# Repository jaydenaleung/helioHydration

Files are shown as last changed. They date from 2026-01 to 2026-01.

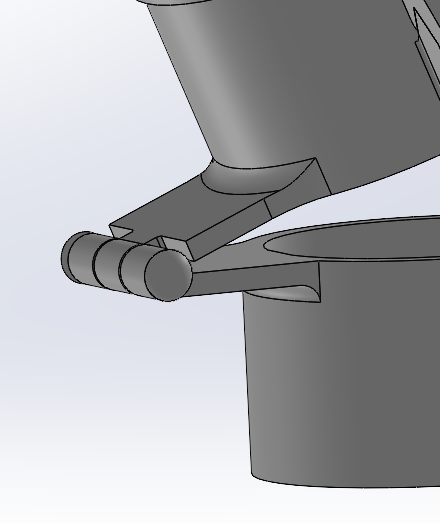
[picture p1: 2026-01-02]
filter/cad/production/render-5.png

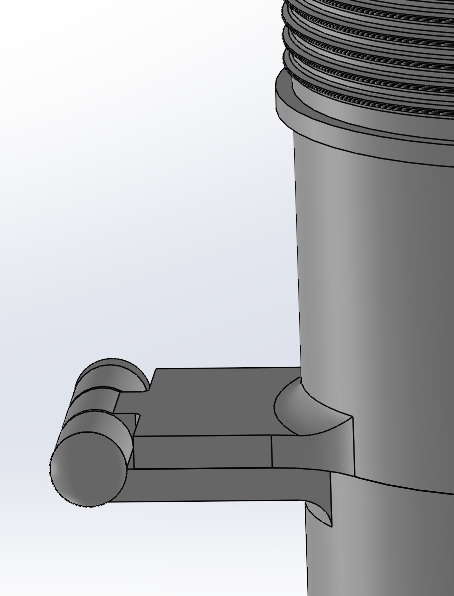
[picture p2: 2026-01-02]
filter/cad/production/render-2.png

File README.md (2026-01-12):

# Helio Hydration - 3-Stage SODIS-Enhancing Water Bottle
Three-stage solar water disinfection (SODIS)-enhancing low-cost water bottle for NGO distribution to underserved and impoverished areas globally.



## Overview

This is a custom-designed water bottle to enhance solar water disinfection, a process where people utilize the sun's UV rays to kill bacteria in contaminated water, especially in places without access to clean water. The goal of this project is to design an efficient device that NGOs can buy and distribute to crisis areas around the world. The three stages are fiber membrane filtration, SODIS enhancement via clearer plastic materials, reflection, and heat-trapping, and indication/readiness tracking.

**Total time spent: 25.5 hours**

## Why I Created This Project

This project was created with a team for the Conrad Challenge: Water Challenge (though we decided not to submit it in the end). However, all the work for this Blueprint project was entirely my own - the team helped with other areas of the research and project. When brainstorming, we wanted to create a project that would have a 'wow' factor for Conrad Challenge judges, a real impact on the world and global issues, and a technically challenging aspect. After conducting much research around the field, we settled on this idea because we saw that SODIS relied too much on having perfectly sunny weather and non-turbid water. Indication was also an issue since people didn't know when it was truly disinfected.

## How It Works & Implementation

The mechanical structure is comprised of a body, a filter, and an indicator with its housing. The body is parabolic 100mm from the ground, and cylindrical until it reaches a height of ~227mm. Its largest diameter is 120mm. The filter mechanism is a clamp with a twist cap for the membrane fiber filter. The indicator uses the DS18B20 temperature sensor in conjunction with the GUVA-S12SD to calculate log reductions of E. coli.

Using the OneWire and DallasTemperature Arduino libraries, both the measured voltage from the UV photodiode sensor and the Celsius temperature from the temperature are gleaned. The following theoretical function calculates the number of log reductions at a specific time:



For the Arduino MCU, this function is used (using a discrete delta t):



I quite enjoyed applying the volume revolution and bacterial decay formulas I learned from AP Calculus BC this year. I've never really had a project where my class knowledge helped me so much. See the journal for more details.

## Bill of Materials (BOM)

| Name | Quantity | Price (per part) | Link |
| --- | --- | --- | --- |
| GUVA-S12SD UV Sensor Photodiode | 1 | $1.76 | https://www.aliexpress.us/item/3256806350705812.html |
| DS18B20 Temperature Sensor | 1 | $0.2328 | https://jlcpcb.com/partdetail/MSKSEMI-DS18B20MS/C5379069 |
| Ceramic Capacitor SMD | 2 | $0.0007 | https://jlcpcb.com/partdetail/1907-0402CG220J500NT/C1555 |
| Electrolytic Capacitor SMD | 2 | $0.0332 | https://jlcpcb.com/partdetail/14236-CL31A106KBHNNNE/C13585 |
| 4.7kΩ SMD Resistor | 1 | $0.0006 | https://jlcpcb.com/partdetail/26643-0402WGF4701TCE/C25900 |
| 10kΩ SMD Resistor | 1 | $0.001 | https://jlcpcb.com/partdetail/16079-0603WAJ0103T5E/C15401 |
| ATMEGA328P-PU Microcontroller | 1 | $2.2431 | https://jlcpcb.com/partdetail/MicrochipTech-ATMEGA328PPU/C33901 |
| LM7805-TO220 Voltage Regulator | 1 | $0.2084 | https://jlcpcb.com/partdetail/6334298-LM7805CT/C5444281 |
| Crystal Oscillator 16MHz | 1 | $0.1038 | https://jlcpcb.com/partdetail/TAITIENElec-XIHCELNANF16MHZ/C295075 |
| Probe Housing | 1 | $0.3170 | https://www.aliexpress.us/item/3256807782132862.html |
| Epoxy resin | ~1 mL | $0.01 | https://www.walmart.com/ip/Epoxy-Resin-1-Gallon-Kit-Art-Resin-for-DIY-Jewelry-Tabletops-Crystal-Clear-High-Performance-Resin-Epoxy/5478464246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\_27795 |
| Membrane fiber filter | 1 | $0.29 | https://grupovoces.com/products/47mm-glass-fiber-filters-advantec-gc-90-100-pk-advantec |
| Clarified polypropylene (PP) | ~7.5 g | $0.0075 | Would need to contact a factory or ODM. Price taken from internet averages. |
| JLCPCB PCB | 1 | $1.06 ($7.45 with PCBA) | https://jlcpcb.com/ |
| **Total** | | | **$6.34**/bottle ($12.73 with PCBA) |

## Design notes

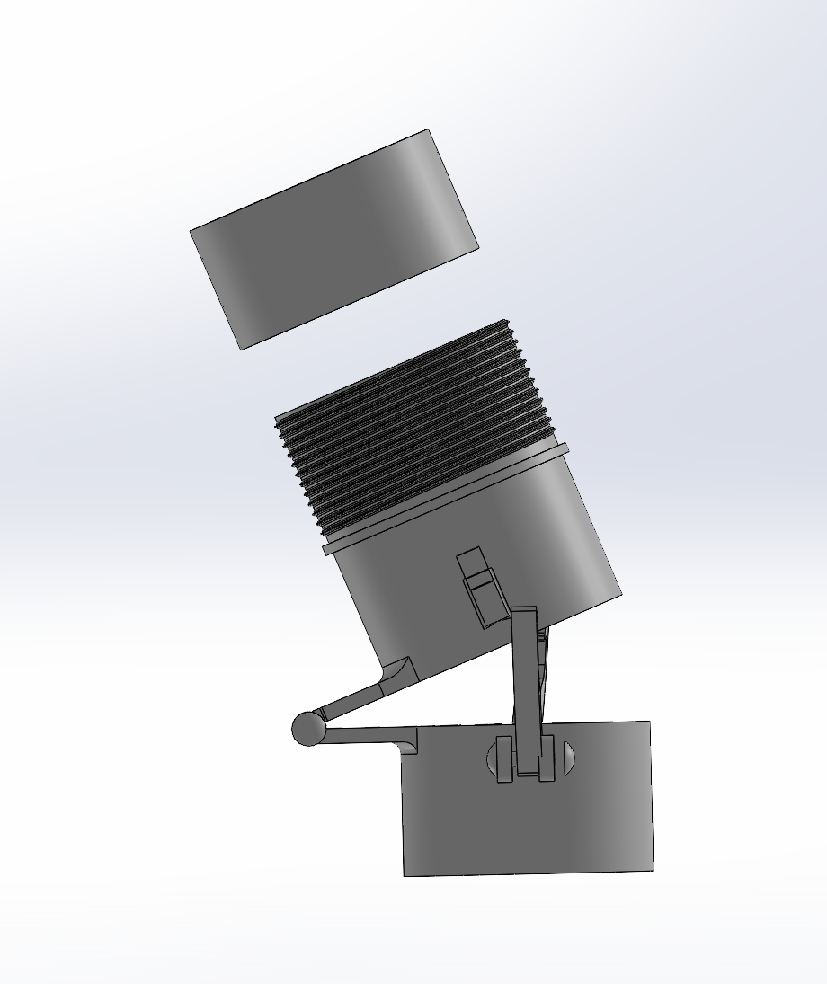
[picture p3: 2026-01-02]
filter/cad/production/render-7.png

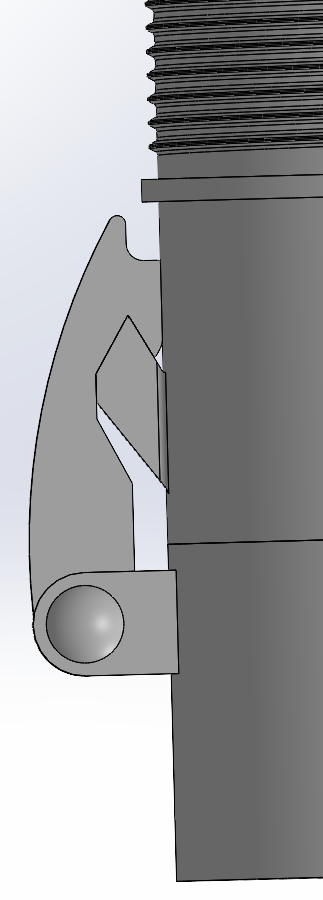
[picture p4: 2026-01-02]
filter/cad/production/render-3.png

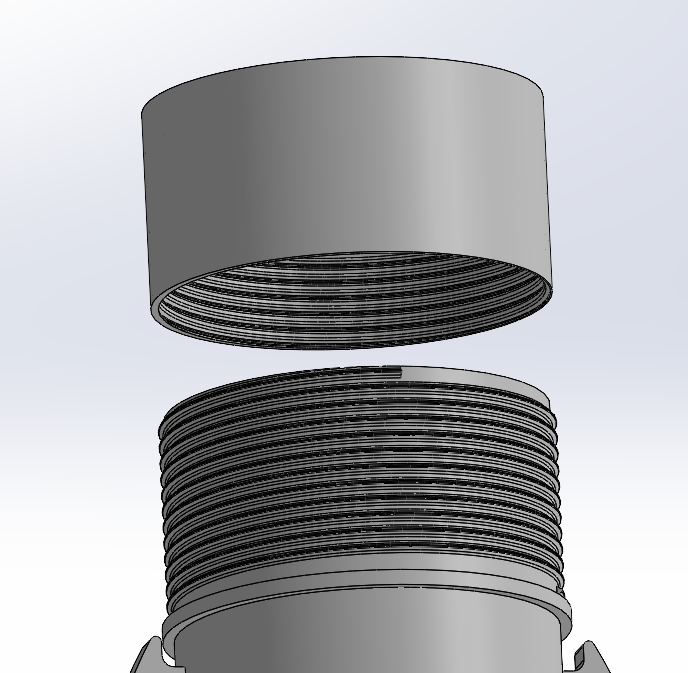
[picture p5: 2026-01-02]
filter/cad/production/render-4.png

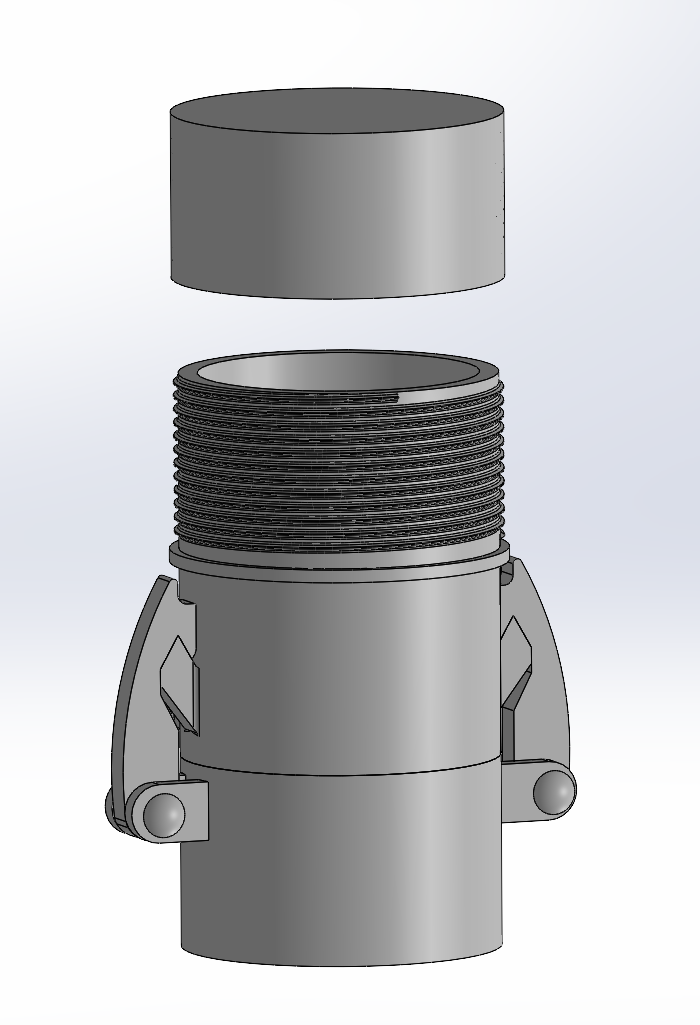
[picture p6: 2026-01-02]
filter/cad/production/render-1.png

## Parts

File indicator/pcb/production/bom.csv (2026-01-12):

Designator | Footprint | Quantity | Value | LCSC Part #
C1, C2 | 0402 | 2 | 22pF ceramic
C3, C4 | 1206 | 2 | 10µF-50V electrolytic
R1 | 0402 | 1 | 4.7kΩ
R3 | 0603 | 1 | 10kΩ
U2 | SZFYDOSH_11x27mm_Sensor | 1 | GUVA-S12SD
U3 | DIP-28_W7.62mm | 1 | ATmega328P-P
U4 | TO-220-3_Vertical | 1 | LM7805_TO220
Y1 | Crystal_HC49-U_Vertical | 1 | CrystalOscillator_16MHz

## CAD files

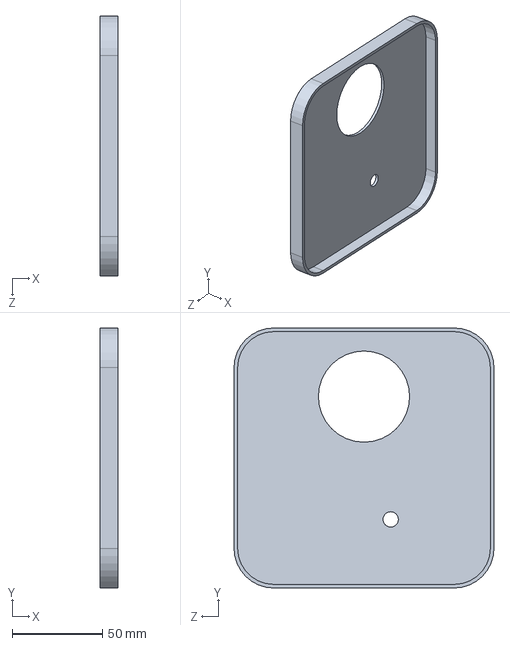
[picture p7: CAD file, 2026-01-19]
body/adapter.SLDPRT
10.0 x 144.0 x 144.0 mm

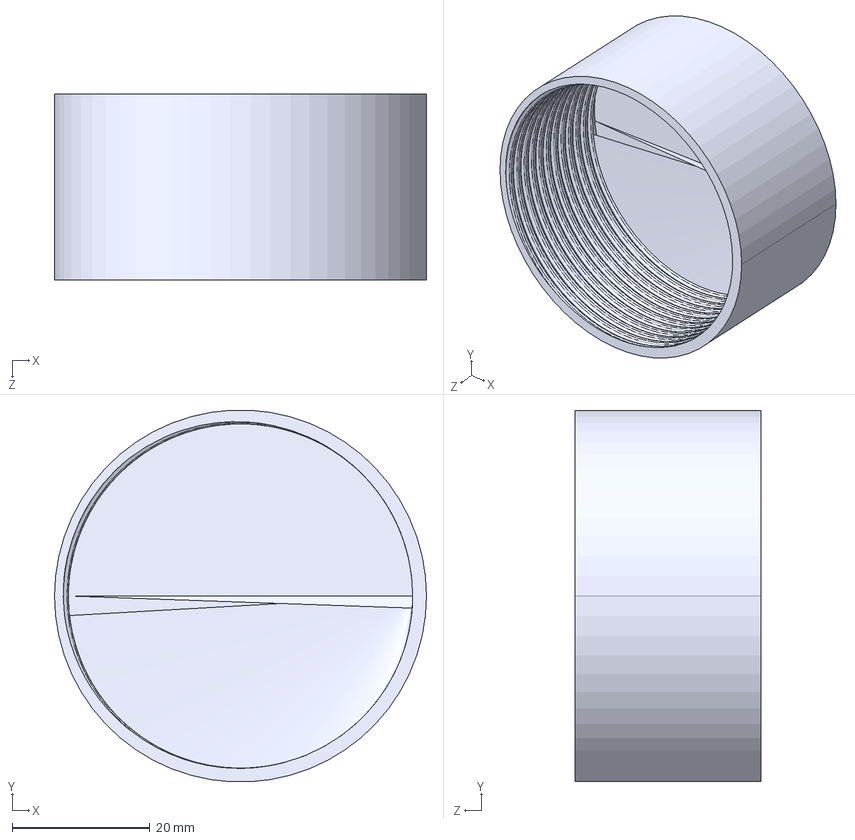
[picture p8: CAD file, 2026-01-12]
filter/cad/production/cap.STEP
54.0 x 53.9 x 27.0 mm

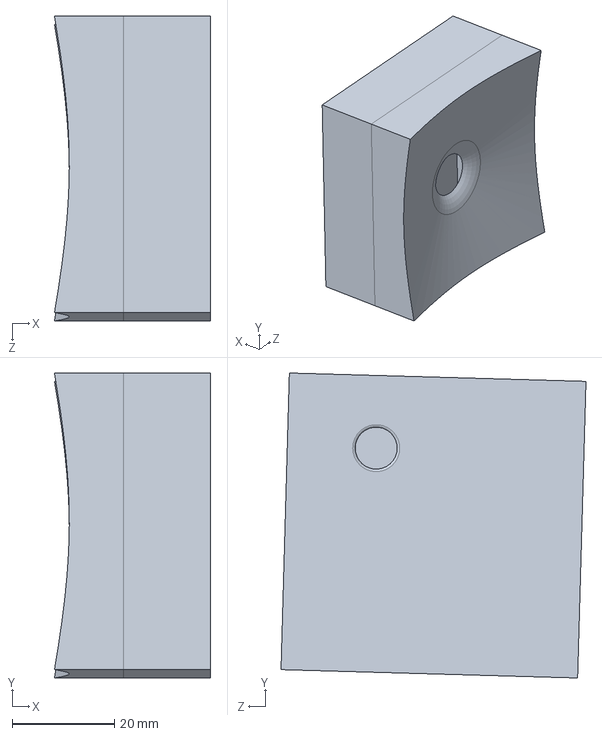
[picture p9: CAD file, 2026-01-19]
indicator/cad/housing.SLDPRT
30.5 x 59.6 x 59.6 mm

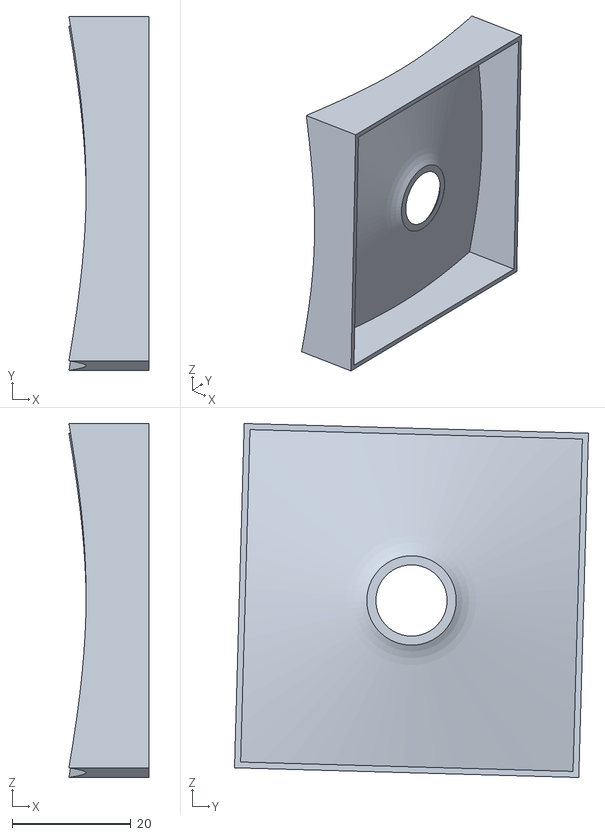
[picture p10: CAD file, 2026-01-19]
indicator/cad/production/housing-top.STL
13.5 x 59.6 x 59.6

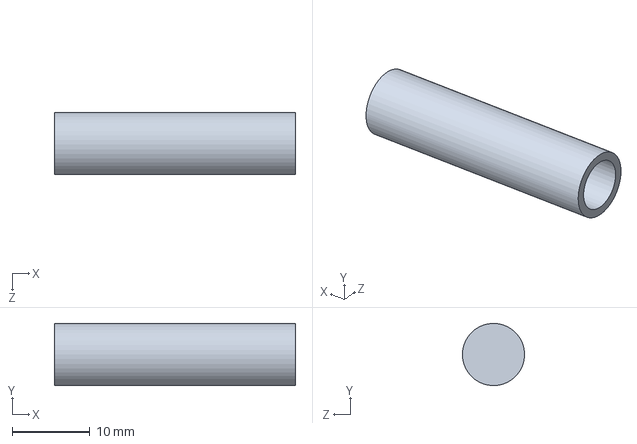
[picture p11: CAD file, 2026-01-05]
indicator/cad/refs/models/probe.SLDPRT
31.0 x 7.99 x 8.00 mm

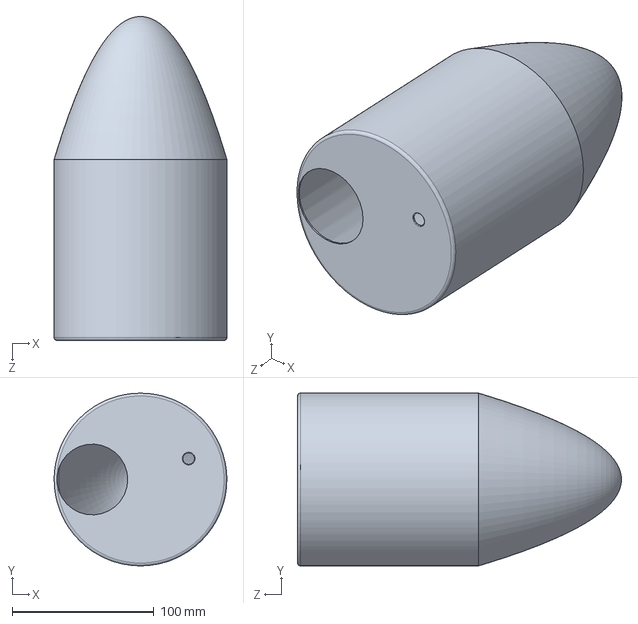
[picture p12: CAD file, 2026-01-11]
body/Body1.SLDPRT
122.0 x 122.0 x 228.8 mm

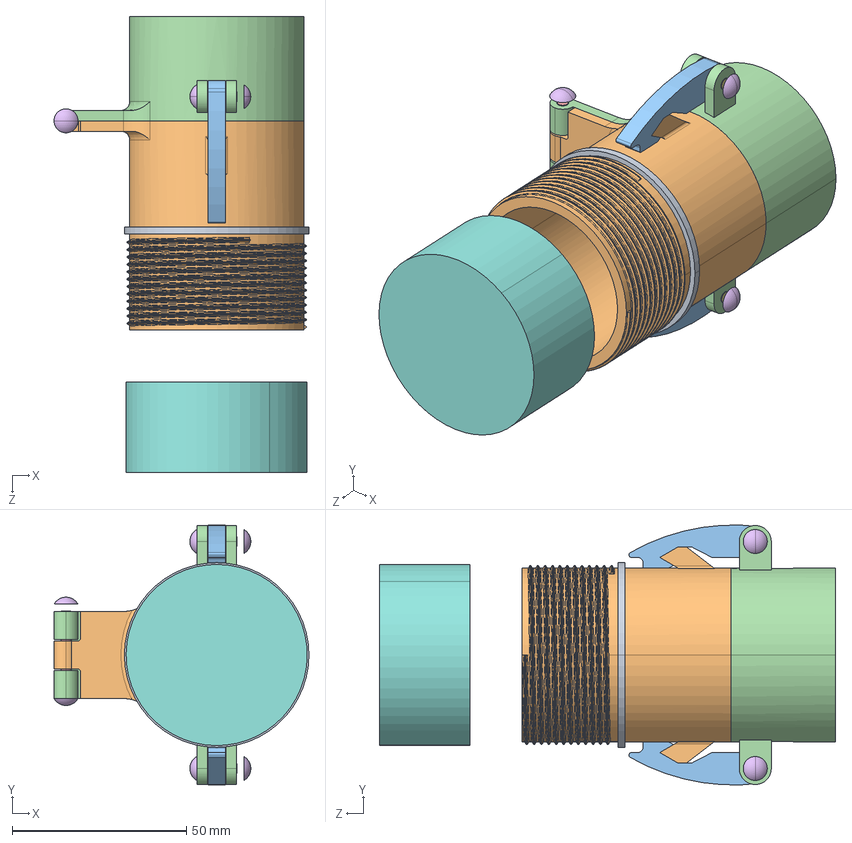
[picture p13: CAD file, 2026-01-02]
filter/cad/production/master_beta.STEP
73.2 x 74.6 x 131.0 mm
clip x 2
hinge_pin
clip_pin x 2
cap

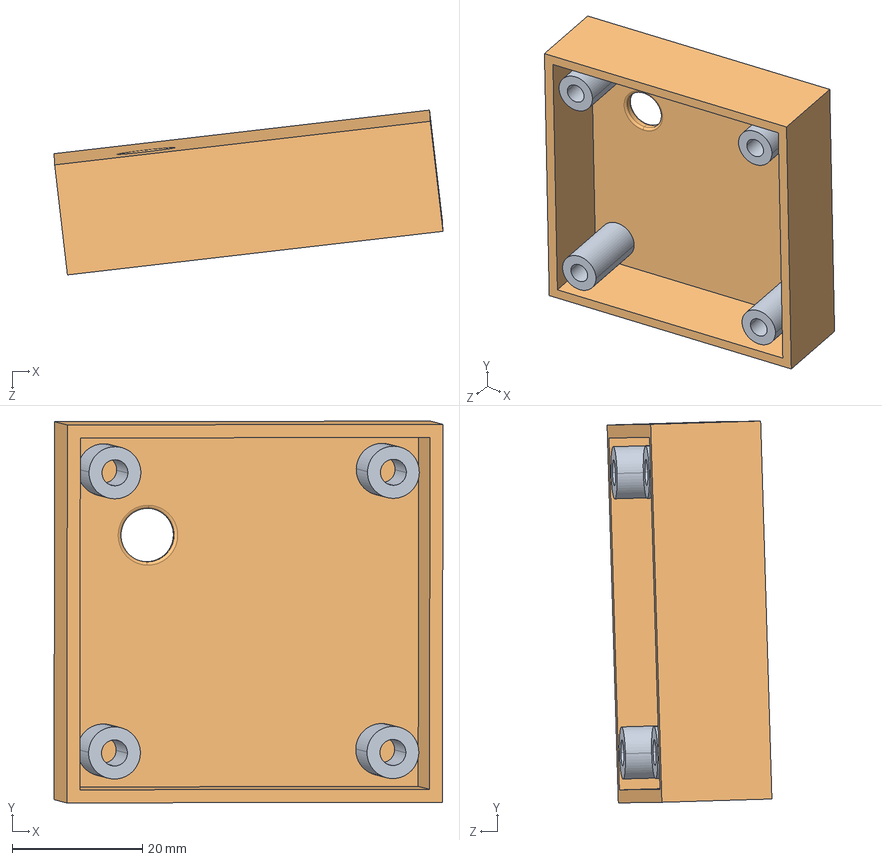
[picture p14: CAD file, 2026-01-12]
indicator/cad/production/housing-bottom.STEP
59.7 x 58.6 x 25.3 mm
standoff x 4
housing

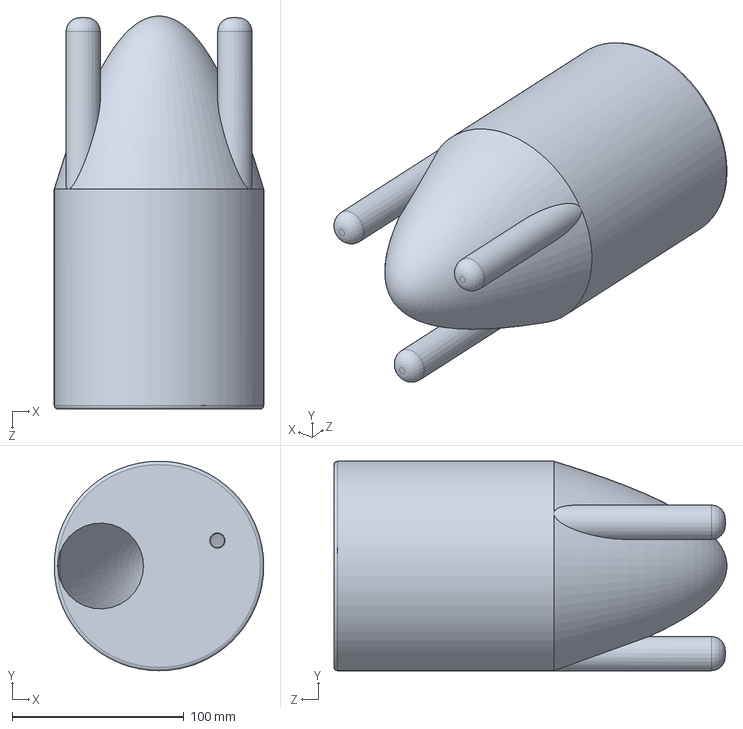
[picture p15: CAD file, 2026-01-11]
body/body.SLDPRT
122.0 x 122.0 x 228.8 mm

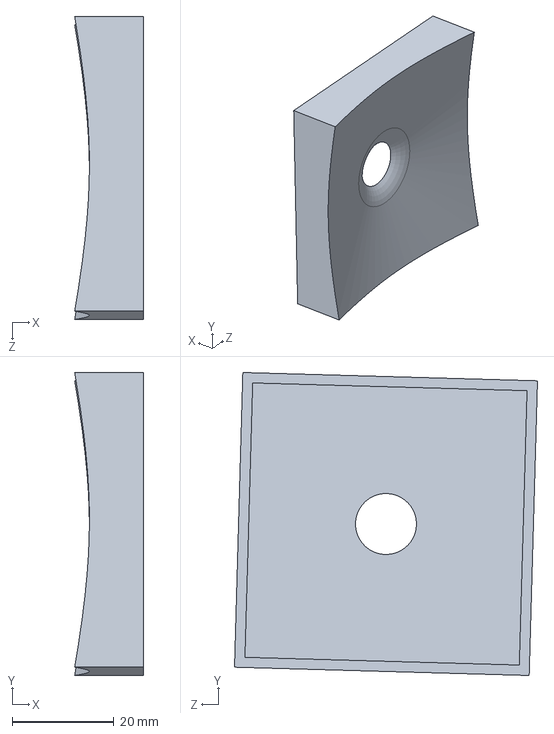
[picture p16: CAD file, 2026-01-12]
indicator/cad/Body2.SLDPRT
13.5 x 59.6 x 59.6 mm

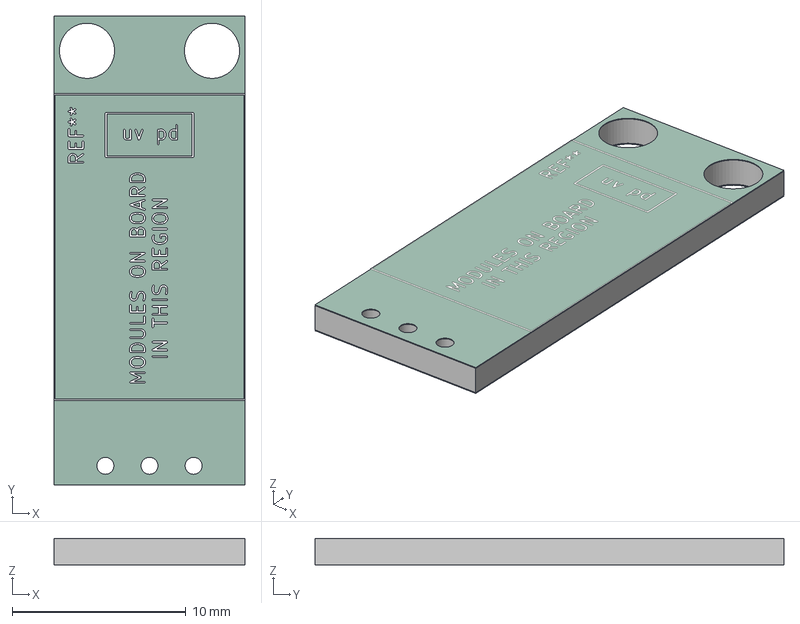
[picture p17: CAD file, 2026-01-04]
indicator/cad/refs/models/guva-s12sd_SZFYDOSH-11x27mm.step
11.0 x 27.0 x 1.64 mm
helioHydration_indicator_silkscreen
helioHydration_indicator_soldermask
helioHydration_indicator_PCB

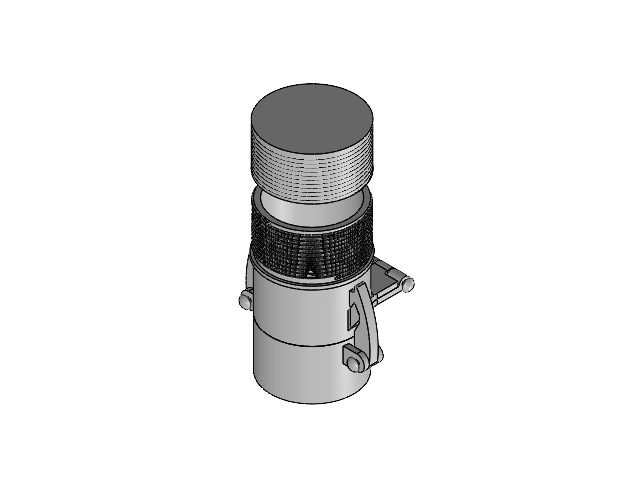
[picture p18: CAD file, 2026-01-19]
filter/cad/filter.SLDASM
clip x 2
hinge_pin
clip_pin x 2
cap

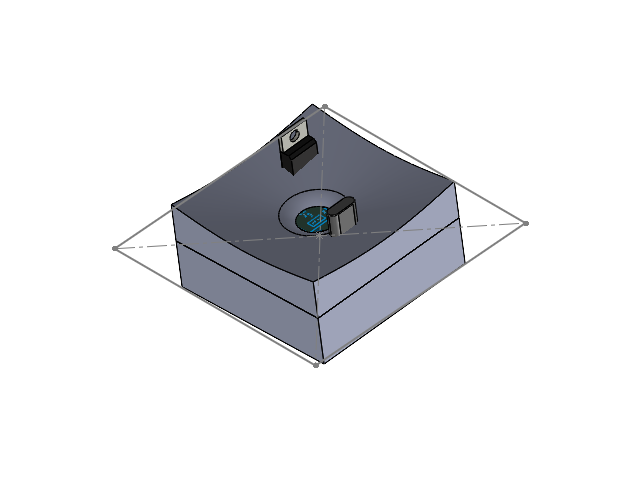
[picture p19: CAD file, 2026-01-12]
indicator/cad/indicator.SLDASM
helioHydration_indicator_silkscreen.step
helioHydration_indicator_soldermask.step
helioHydration_indicator_PCB.step
C_0402_1005Metric.step x 2
TO-220-3_Vertical.step
C_1206_3216Metric.step x 2
R_0402_1005Metric.step
DIP-28_W7.62mm.step
R_0603_1608Metric.step
Crystal_HC49-U_Vertical.step
helioHydration_indicator_silkscreen_1.step
helioHydration_indicator_soldermask_1.step
helioHydration_indicator_PCB_2.step
probe
standoff x 4
DS18B20
housing

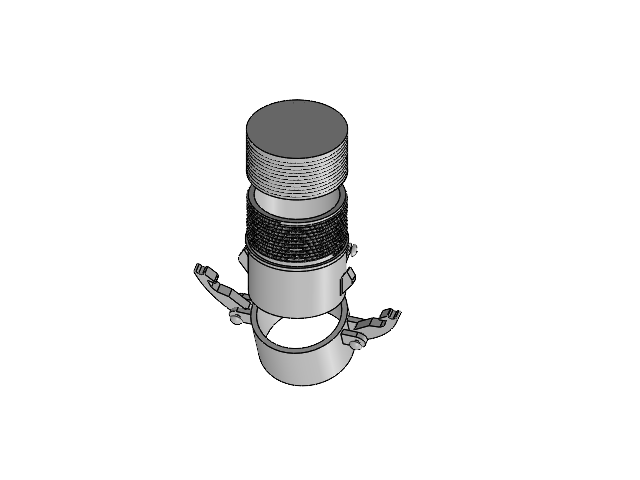
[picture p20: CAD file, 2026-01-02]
filter/cad/filter_exploded.SLDASM
hinge_pin
clip_pin x 2
cap
clip x 2

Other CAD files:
filter/cad/hinge_assempreview_notneeded.SLDASM
body/production/adapter.STEP
filter/cad/cap.SLDPRT
indicator/cad/refs/models/DS18B20.SLDPRT
body/production/adapter.STL
filter/cad/body_1.SLDPRT
filter/cad/body_2.SLDPRT
filter/cad/clip.SLDPRT
filter/cad/clip_pin.SLDPRT
filter/cad/hinge_1.SLDPRT
filter/cad/hinge_2.SLDPRT
filter/cad/hinge_pin.SLDPRT
indicator/cad/Body1.SLDPRT
indicator/cad/refs/models/helioHydration_indicator_pcb.step
indicator/cad/standoff.SLDPRT

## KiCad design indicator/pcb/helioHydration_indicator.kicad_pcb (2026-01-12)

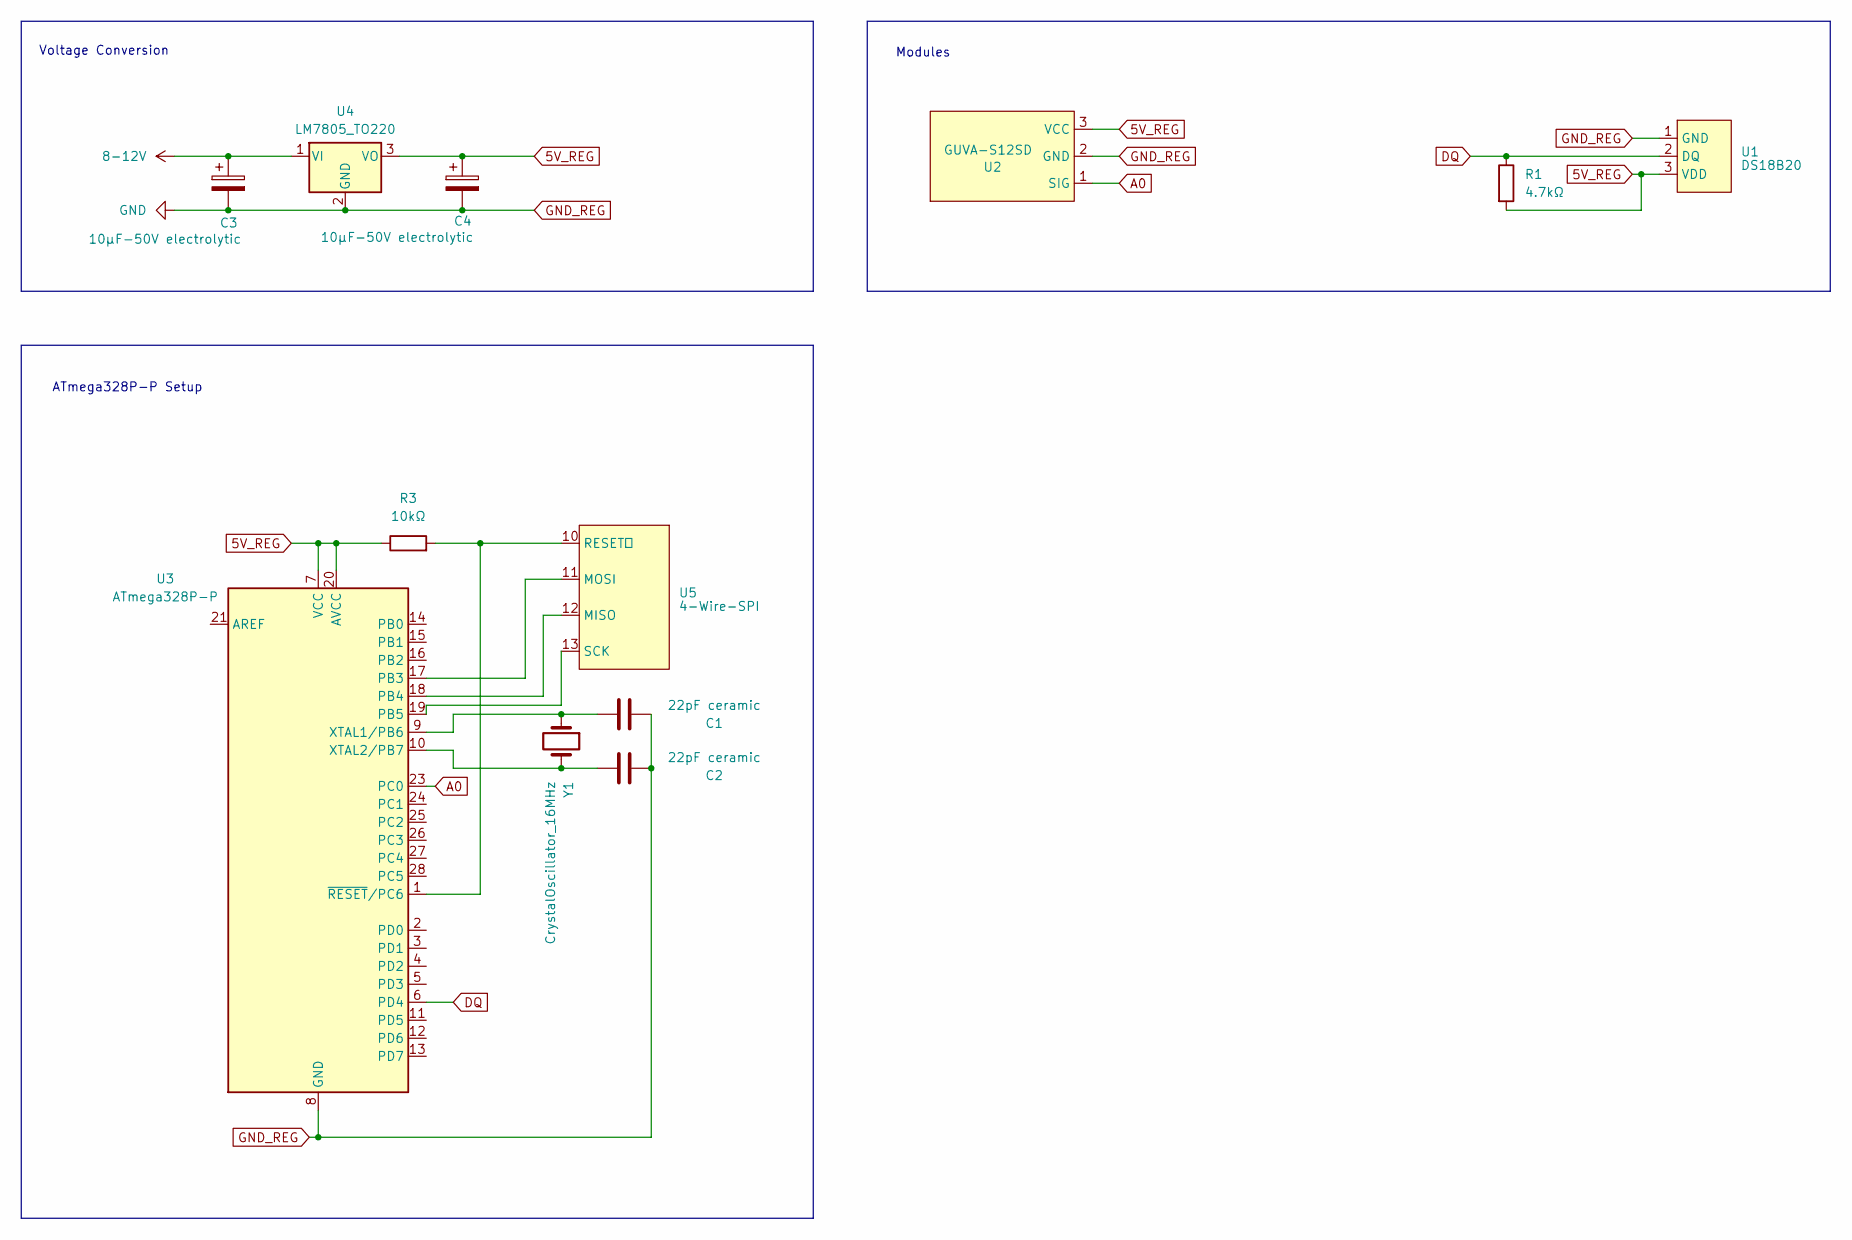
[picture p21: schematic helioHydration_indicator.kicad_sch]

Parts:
C1, C2: 22pF ceramic; C_0402_1005Metric
C3, C4: 10µF-50V electrolytic; C_1206_3216Metric
R1: 4.7kΩ; R_0402_1005Metric
R3: 10kΩ; R_0603_1608Metric
U1: DS18B20; DS18B20-MSKSEMI; Manufacturer Part .; LCSC Part Name .
U2: GUVA-S12SD; SZFYDOSH_11x27mm_Sensor
U3: ATmega328P-P; DIP-28_W7.62mm
U4: LM7805_TO220; TO-220-3_Vertical
U5: 4-Wire-SPI
Y1: CrystalOscillator_16MHz; Crystal_HC49-U_Vertical

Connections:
5V_REG: C4.1, R1.2, R3.1, U1.3 (VDD), U2.3 (VCC), U3.7 (VCC), U3.20 (AVCC), U4.3 (VO)
8-12V: C3.1, U4.1 (VI)
A0: U2.1 (SIG), U3.23 (PC0)
DQ: R1.1, U1.2 (DQ), U3.6 (PD4)
GND_REG: C1.1, C2.2, C3.2, C4.2, U1.1 (GND), U2.2 (GND), U3.8 (GND), U3.22 (GND), U4.2 (GND)
unnamed: U3.17 (PB3), U5.11 (MOSI)
unnamed: U3.18 (PB4), U5.12 (MISO)
unnamed: U3.19 (PB5), U5.13 (SCK)
unnamed: C1.2, U3.9 (XTAL1/PB6), Y1.1
unnamed: C2.1, U3.10 (XTAL2/PB7), Y1.2
unnamed: R3.2, U3.1 (~RESET/PC6), U5.10 (RESET)

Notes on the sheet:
ATmega328P-P Setup
Voltage Conversion
Modules

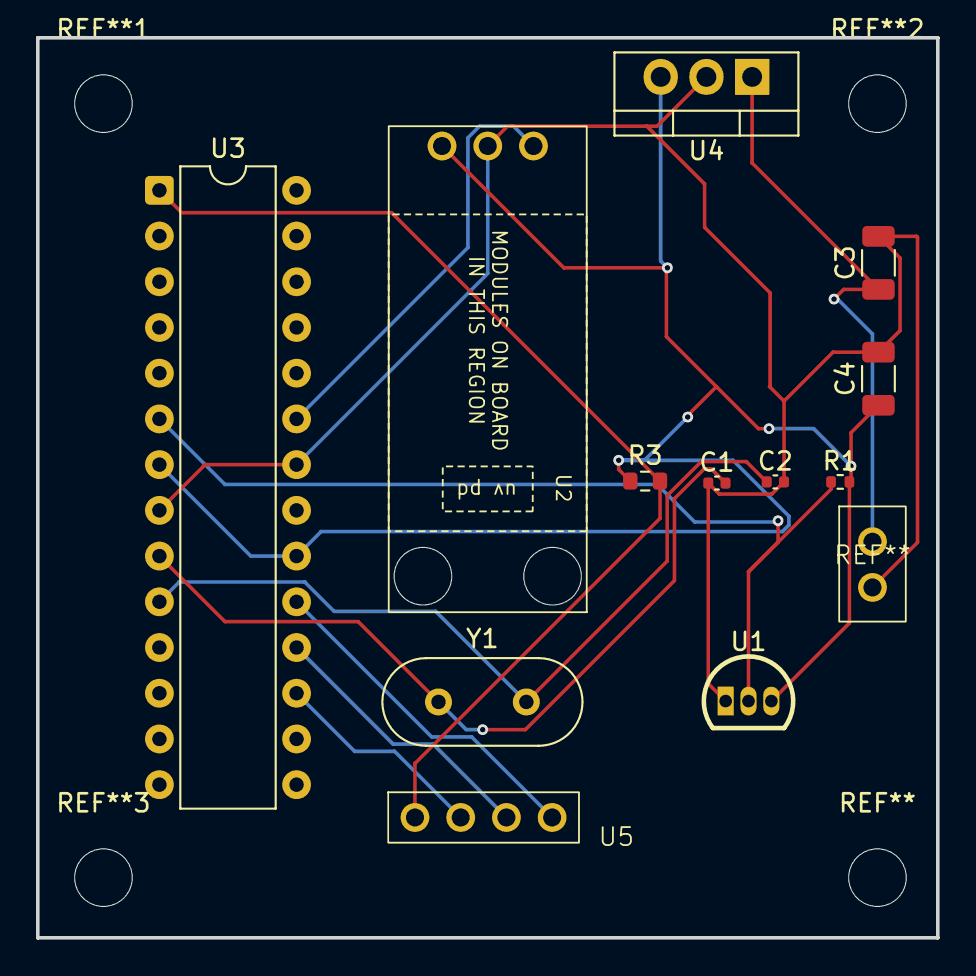
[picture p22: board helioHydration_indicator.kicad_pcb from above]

Board: 2 copper layers, 50.0 x 50.0 mm, 12 parts (0 on the bottom side), 11 nets.

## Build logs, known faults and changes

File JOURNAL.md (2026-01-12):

# Ongoing Journal

See my journal here: https://blueprint.hackclub.com/projects/7328.

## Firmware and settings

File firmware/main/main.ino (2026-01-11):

// ELECTRONICS
#include "OneWire.h"
#include "DallasTemperature.h"

#define DQ_ONE_WIRE 4
#define UV_PIN A0;

OneWire oneWire(DQ_ONE_WIRE);
DallasTemperature sensors(&oneWire);

// CALCULATIONS
// See JOURNAL.md for the formula
bool active = true;

double L = 0.0;
double sum = 0.0;

double sigma = 0.03;
double C_PD = 1.0;
double coeff = sigma*C_PD/log(10); // log() is ln function

double delta_prev = 0.0;
double delta;
double delta_sec;

// Measurements
double V_PT; // photodiode voltage
double temp; // temperature measurement, celsius
double K_T; // temperature killing term

void initDelta() { // call initDelta() then updateDelta() in setup()
    delta = millis()-delta_prev;
    delta_sec = delta/1000.0;
}

void updateDelta() {
    delta_prev = delta;
    delta = millis()-delta_prev;
    delta_sec = delta/1000.0;
}

void updateVPT() {
    int uvLevel = analogRead(UV_PIN);
    V_PT = uvLevel * (5.0 / 1023.0);
}

void updateTemp() {
    sensors.requestTemperatures();
    temp = sensors.getTempCByIndex(0); // the index 0 refers to the first device
}

void updateTempTerm() {
    if (temp < 40) {
        K_T = 1.0;
    } else {
        K_T = pow(1.1036,temp-44.6958);
    }
}

// SETUP AND LOOP
void setup() {
    Serial.begin(9600);

    sensors.begin();
    delay(60*1000); // wait 1 min for sensors to init

    initDelta();
    updateDelta();
}

void loop() {
    if (active) {
        updateVPT();
        updateTemp();
        updateTempTerm();
        updateDelta();
        
        sum += V_PT*K_T*delta;
        L = coeff*sum;

        if (L >= 3.0) {
            active = false;
            Serial.println("Water successfully disinfected.");
        }
    }
 }

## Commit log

2026-01-02 cad filter beta
    [body_1.SLDPRT, body_2.SLDPRT, cap.SLDPRT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]
2026-01-02 fix cap, upload step and stl files
    [cap.SLDPRT, master.SLDASM, master.STEP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]
2026-01-02 added render
    [master.SLDASM, master_beta.STEP, master_exploded.SLDASM]
2026-01-04 finish indicator pcb and schematic
    [guva-s12sd_SZFYDOSH-11x27mm.step, helioHydration_indicator.kicad_pcb, helioHydration_indicator.kicad_sch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]
2026-01-05 make indicator housing
    [DS18B20.SLDPRT, helioHydration_indicator.kicad_pcb, housing.SLDPRT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]
2026-01-11 finishing touches and full assy
    [Body1.SLDPRT, body.SLDPRT, filter.SLDASM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]
2026-01-12 update text
    [BOM.csv]
2026-01-12 update pcb
    [bom.csv, helioHydration_indicator.csv, helioHydration_indicator.kicad_pcb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]
2026-01-12 update gerbers organization
2026-01-12 updated bom
    [BOM.csv, bom.csv, helioHydration_indicator.csv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]
2026-01-12 update bom
    [bom.csv, positions.csv]
2026-01-12 modified for 3d printing
    [Body1.SLDPRT, Body2.SLDPRT, cap.SLDPRT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]
2026-01-19 make adapter
    [adapter.SLDPRT, adapter.STEP, filter.SLDASM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]
2026-01-19 revert this
    [housing.SLDPRT, indicator.SLDASM]
2026-01-19 Revert "revert this"
    This reverts commit 2f62f56bc3b80bfbb911c09e7c4823a3de9b39f3.
    revert commit
    [housing.SLDPRT, indicator.SLDASM]
2026-01-19 fix housing top
    [housing-top.STEP, housing-top.STL]
